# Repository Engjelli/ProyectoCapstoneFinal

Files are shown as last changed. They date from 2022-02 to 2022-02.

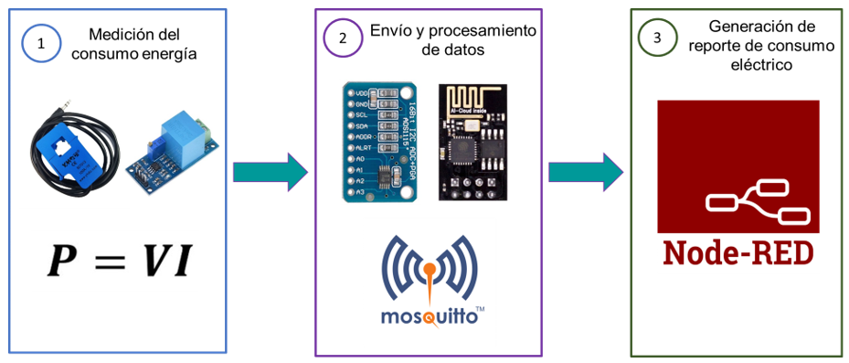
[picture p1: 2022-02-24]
Imagenes/Imagenes_reporte/01_diagrama_bloques_proyecto.PNG

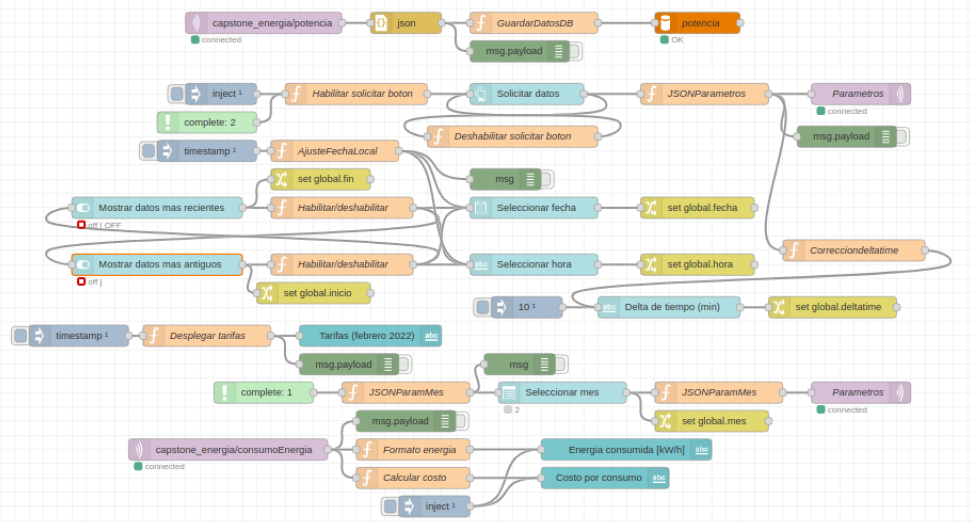
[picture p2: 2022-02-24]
Imagenes/Imagenes_reporte/08_flow_Node_Red1.PNG

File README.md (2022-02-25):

# ProyectoCapstoneFinal
Este proyecto muestra los patrones de consumo eléctrico durante el uso de los ordenadores.

**Nombre del proyecto**: Sistema de monitoreo sobre el consumo energético en ordenadores por medio del IoT

**Fecha de inicio del proyecto**: 12/12/21

**Fecha de conclusión del proyecto**: 22/02/22

**Descripción**: El equipo muestra los patrones de consumo eléctrico durante el uso de los ordenadores.

**Aplicaciones**: Delimitación a uso en ordenadores

## Objetivo general

 - Evaluar cuantitativamente el desempeño energético en ordenadores por medio del monitoreo de datos haciendo uso de plataformas y herramientas IoT.

## Objetivos particulares

 - Determinar el consumo energético en ordenadores a partir de las mediciones de voltaje y corriente almacenadas en una base de datos. 
 
 - Analizar los datos de consumo energético por medio de cálculos y gráficas con las mediciones  - almacenadas en la base de datos. 
 
 - Monitorear recursos de hardware y desempeño energético en ordenadores a través de Node Red utilizando paneles de control personalizados.

## Justificación

Si utilizamos una PC para tareas básicas como procesamiento de textos o incluso poder revisar nuestras redes sociales es probable que nuestro ordenador no demande demasiada energía. No obstante, si se trata de tareas más exigentes como edición de video, juegos o algún software en específico pueden causar un aumento considerable en el consumo de energía, además de un incremento en los costos en el recibo de luz. 

Por consiguiente, el sistema de monitoreo que se propone tiene como finalidad apoyar a los usuarios de una oficina, empresa e incluso en un hogar que cuenten con varios ordenadores conocer su consumo energético. Con base en esta información se puede evaluar y tomar las medidas necesarias para poder disminuir dicho consumo y reducir los costos en el recibo de luz. 

## Integrantes del equipo

María de los Ángeles Lino Suárez. 

Github: https://github.com/Engjelli

Jessica Arzate Martínez. 

Github: https://github.com/Jessica2123

Fernando Daniel Ramírez Cruz. 

Github: https://github.com/ferdanrc

**Validado por**: Paloma Vilchis y Hugo Vargas

## Contenido temático

**Productos**: 

**Alcances**: 
 - Oficinas inteligentes.
 - Infraestructuras on-premise.
 - Conocer patrones en consumo de energía.

## Funcionamiento del proyecto

Video del funcionamiento del proyecto: https://youtu.be/SWLC1IwsTZM

## Requisitos

### Hardware

**1. Alimentación del circuito 5V y 3.3V**

 - Cargador USB
 - Conector USB
 - Fuente 3.3V
 - Contacto para soldar
 - Cable duplex
 - Cable con clavija

**2. Módulos de interface  y conversión de datos**

 - Microcontrolador
 - ADC
 
**3. Sensores y material de acoplamiento**

 - Sensor de corriente
 - Sensor Voltaje
 - Jack Hembra 3.5mm
 - Cables Dupont
 
**4. Componentes para filtros y conexión del circuito**

 - Resistencias 
 - Capacitores 
 - Push button
 - Interruptor
 - Alambre Negro
 - Alambre Rojo

**5. Material para la carcasa del circuito**

 - Gabinete
 - Soldadura
 - Protoboard
 - Base para CI
 - Header Macho
 - Header Hembra

### Software

 - Node Red
 - Arduino con librerias MQTT y ESP8266

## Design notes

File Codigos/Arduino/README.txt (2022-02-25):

#README

##Instalacion de librerias

Instalar tarjeta para el ESP01 (basado en ESP8266):

http://arduino.esp8266.com/stable/package_esp8266com_index.json

Instalar las librerias:

 - Wire
 - EspMQTTClient

##Para cargar programas al ESP01

 1. Verificar que el pin 5 (GPIO0) esté conectado a tierra (colocar el switch correspondiente a tierra) para programarlo. 
 2. Presionar el botón de reset (push button para el pin 6). Aparece un mensaje en el puerto serial del IDE del Arduino a 74880 baud que indica que está en "boot mode".
 3. Cargar el programa. 

##Para ejecutar programas en el ESP01

 1. Al correr el programa, conectar el pin 5 (GPIO0) al ADS1115. 
 2. Presionar el botón de reset (push button para el pin 6). Aparece un mensaje en el puerto serial del IDE del Arduino a 74880. 
 3. El programa debe ejecutarse.

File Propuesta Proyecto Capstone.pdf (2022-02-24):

## Proyecto Capstone

Nombre:

Sistema de monitoreo sobre el consumo energético en ordenadores por medio del IoT

Asesora:

Vilchis León Paloma Alejandra

Integrantes:

Ramírez Cruz Fernando Daniel

Lino Suárez María de los Ángeles

Arzate Martínez Jessica

## Contenido

### 6.2.2 Convertidor analógico/digital externo, utilizando protocolo de

### 1. Introducción

Hoy en día la tecnología es necesaria en el ambiente profesional y personal, tanto que la mayoría de los dispositivos necesitan estar conectados a una toma corriente o ser cargados, diferente al siglo XIX en México donde solo se necesitaba la energía para iluminar las calles y viviendas en las noches. Actualmente hay muchos dispositivos que consumen energía eléctrica, lo que ha provocado que este consumo aumente y por tanto también los gastos por consumo eléctrico.

Los ordenadores se utilizan cotidianamente, entonces conocer su consumo de energía por máquina, por ejemplo en una oficina, puede optimizar el consumo de kWh y por lo tanto ahorrar así cómo planear su uso. El consumo de un ordenador puede convertirse en un indicador importante en términos de gastos de luz al año. Incluso, este cálculo puede ser significativo en lugares donde haya varios ordenadores, el costo por consumo eléctrico puede dispararse si no se tiene control sobre su uso, sobre todo si son potentes [1].

En este proyecto se pretende implementar un sistema de monitoreo sobre el consumo de energía en ordenadores haciendo uso de las herramientas y plataformas que nos proporciona el IoT. La delimitación del ambiente es un conjunto de varias computadoras funcionando de manera simultánea, por medio de sensores se obtendrán mediciones de corriente-voltaje, con los cuales se realizarán algunos cálculos de potencia que permitirán conocer el consumo energético en dichos equipos.

### 2. Objetivo general

Evaluar cuantitativamente el desempeño energético en ordenadores por medio del monitoreo de datos haciendo uso de plataformas y herramientas IoT.

### 3. Objetivos específicos:

1. Determinar el consumo energético en ordenadores a partir de las mediciones de voltaje y corriente almacenadas en una base de datos.
2. Analizar los datos de consumo energético por medio de cálculos y gráficas con las mediciones almacenadas en la base de datos.
3. Monitorear recursos de hardware y desempeño energético en ordenadores a través de Node Red utilizando paneles de control personalizados.

### 4. Justificación

Los ordenadores se han convertido en una parte integral de la sociedad actual. Son máquinas indudablemente poderosas y versátiles y se utilizan para realizar diversas tareas, desde trabajar hasta entretenimiento. Sin embargo, nunca nos preguntamos cuánta energía se puede consumir al realizar diversas tareas en dichos dispositivos [2].

Si utilizamos una PC para tareas básicas como procesamiento de textos o incluso poder revisar nuestras redes sociales es probable que nuestro ordenador no demande demasiada energía. No obstante, si se trata de tareas más exigentes como edición de video, juegos o algún software en específico pueden causar un aumento considerable en el consumo de energía, además de un incremento en los costos en el recibo de luz.

Por consiguiente, el sistema de monitoreo que se propone tiene como finalidad apoyar a los usuarios de una oficina, empresa e incluso en un hogar que cuenten con varios ordenadores conocer su consumo energético. Con base en esta información se puede evaluar y tomar las medidas necesarias para poder disminuir dicho consumo y reducir los costos en el recibo de luz.

Este sistema permite almacenar datos de corriente y voltaje de los equipos haciendo uso de diversas plataformas y herramientas que nos proporciona el Internet de las cosas. Se realizarán algunos cálculos de potencia los cuales permitirán conocer el consumo energético. Los datos obtenidos podrán ser analizados e interpretados haciendo uso de bases de datos y gráficas para generar informes sobre el consumo diario de los equipos. Además, se podrán conocer los procesos de los ordenadores que puedan estar generando un incremento en el consumo de energía.

Si bien, sería complicado dejar de usar nuestros ordenadores por completo dada la situación actual, el poder conocer el consumo energético podría ayudar a que formemos mejores hábitos de uso de dichos equipos. Por ejemplo, si el equipo no se está utilizando no tendría que estar encendido, eliminar procesos que no se utilicen y puedan estar generando mayor consumo, o si se están realizando tareas automáticas podríamos apagar el monitor de nuestra PC.

### 5. Material necesario

La lista de material se presenta a continuación:

- 1 Computadora de bajo costo (Raspberry Pi 3B+)
- 1 Computadora con adaptador para toma de corriente

Adicionalmente, para el medidor de consumo eléctrico:

Medidor de potencia versión Protoboard y versión Impreso

Alimentación del circuito 5V y 3.3V

Notas | Componente | Modelo/Valor | Cantidad | Precio | Subtotal
| Cargador USB | 5V @ 1A | 1 | 95 | 95
(Opcional)** | Conector USB | | 1 | 25 | 25
| Fuente 3.3V | AMS1117 | 1 | 47 | 47
| Contacto para soldar | | 1 | 29 | 29
| Cable duplex | Calibre 18 | 1 | 13 | 13
| Cable con clavija | 1.5m, calibre 18 | 1 | 35 | 35

Módulos de interface y conversión de datos

Microcontrolador | ESP01 | 1 | 59 | 59
ADC | ADS1115 | 1 | 130 | 130

Sensores y material de acoplamiento

Sensor de corriente | SCT013 | 1 | 134 | 134
Sensor Voltaje | ZMPT101B | 1 | 64 | 64
Jack Hembra 3.5mm | | 1 | 9 | 9
Cables Dupont | MH 10cm | 1 | 20 | 20
HH 10cm | 1 | 20 | 20

Componentes para filtros y conexión del circuito

Resistencias | 10k | 6 | 0.7 | 4.2
| R5* | 1 | 0.7 | 0.7
| 220k | 1 | 0.7 | 0.7
Capacitores | 10n | 1 | 2 | 2
| 10uF | 2 | 2 | 4
| 22uF | 1 | 2 | 2
| 100uF | 2 | 3 | 6

Push button | Microswitch 2 pines | 1 | 1 | 1
Interruptor | 1P2T | 1 | 4 | 4
Alambre Negro | 1m | 1 | 3 | 3
Alambre Rojo | 1m | 1 | 3 | 3
Material para la carcasa del circuito
*** | Gabinete | 15x6x9.9 cm | 1 | 179 | 179
| Soldadura | 17 gramos, 60/40 | 2 | 39 | 78
v.Protoboard | Protoboard | 400 puntos | 1 | 29 | 29
v.Impreso | Base para CI | 8 pines | 1 | 5 | 5
| Header Macho | 2x3 | 1 | 3 | 3
1x40 | 1 | 4 | 4
| Header Hembra | 2x4 | 1 | 5 | 5

Precios revisados en UNit Electronics y Steren al 2 de febrero del 2022

Notas adicionales sobre herramientas utilizadas

Se requiere de cautín y soldadura para poder colocar algunos componentes, como el ADS1115, el sensor de corriente y el sensor de voltaje.

**Para abrir el cargador USB, se recomienda utilizar un sargento. Con el sargento se presiona en puntos débiles de la carcasa para abrirla

*** Se requiere un taladro, brocas y limas para colocar los componentes sobre el gabinete

Total(v.Protoboard)*** | 996.6
Total(v.Impreso)*** | 984.6

Costos de envió
Tienda | Precio
UNIT Electronics | 50
Electrónica Steren | Gratis (mayor a 500$)

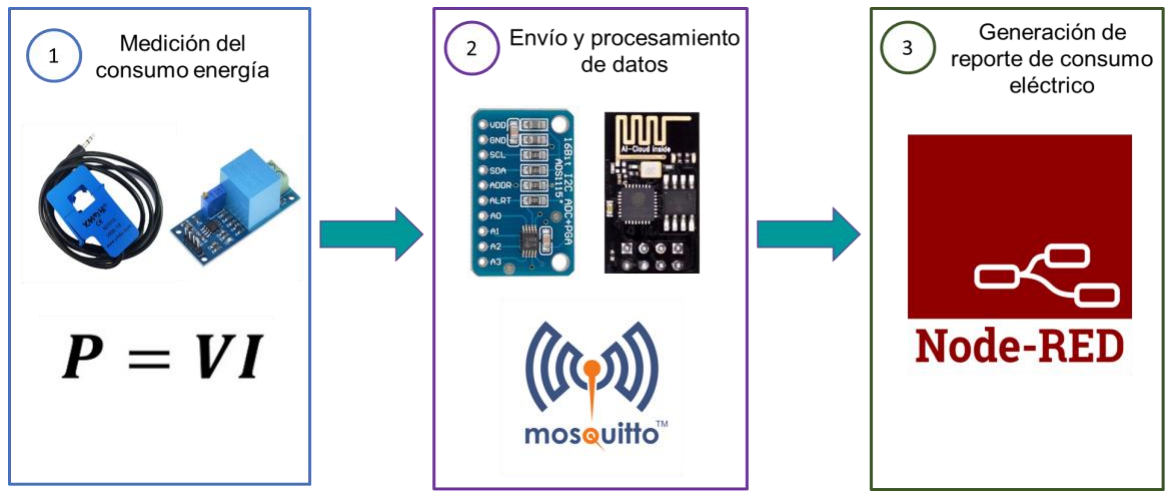
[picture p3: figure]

Fig. 1 Diagrama a bloques del sistema de monitoreo sobre el consumo energético en ordenadores.

### 6. Descripción del proyecto

El diagrama a bloques que representa al sistema de monitoreo sobre el consumo energético en ordenadores, es el siguiente:

A continuación, se realiza de forma general la descripción de cada uno de los bloques que conforman al sistema de monitoreo del consumo energético en ordenadores.

### 6.1 Medición del consumo de energía

En esta etapa se mide voltaje y corriente por medio de sensores y se agregan filtros para separar el ruido de las señales, y así obtener mediciones más confiables. Se presenta el diagrama esquemático completo utilizado:

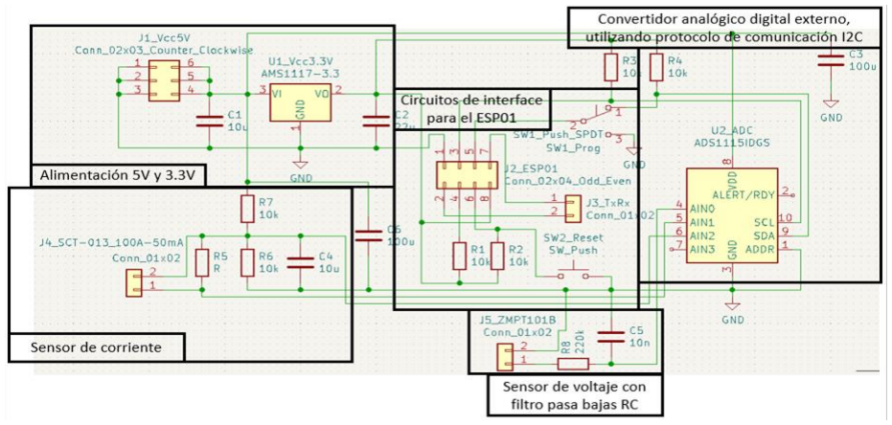
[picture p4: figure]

El circuito completo se compone de las siguientes partes:

2. Alimentación 5V y 3.3V: Contiene los circuitos de alimentación de todo el circuito.
3. Sensor de corriente: Incluye los circuitos para convertir la señal de corriente en señal de voltaje proveniente del sensor de corriente.
4. Sensor de voltaje: Contiene los circuitos y el filtro pasa bajas para el sensor de voltaje.
5. Convertidor analógico digital: Contiene los circuitos para adquirir las señales de los sensores de corriente y voltaje.
6. Circuitos de interface para el ESP01: Contiene los circuitos para cargar programas al ESP01.

A continuación, se realiza una breve explicación del circuito para cada uno de los sensores.

Fig. 2 Diagrama esquemático completo

### 6.1.1 Sensor de corriente

El sensor de corriente utilizado es el SCT-013 de 100A a 50mA. Para ello se utilizan las resistencias R5, R6, R7 y el capacitor C4 mostrados en la figura 3.

- Puesto que este sensor da como salida una corriente de hasta 50mA, se convierte esta señal de corriente en voltaje con la resistencia R5.

Las resistencias R6 y R7 forman un divisor de voltaje para el voltaje de alimentación de 5V, que servirá como voltaje de offset para montar la señal de corriente convertida a voltaje y que pueda ser leída por el convertidor analógico digital ADS1115.

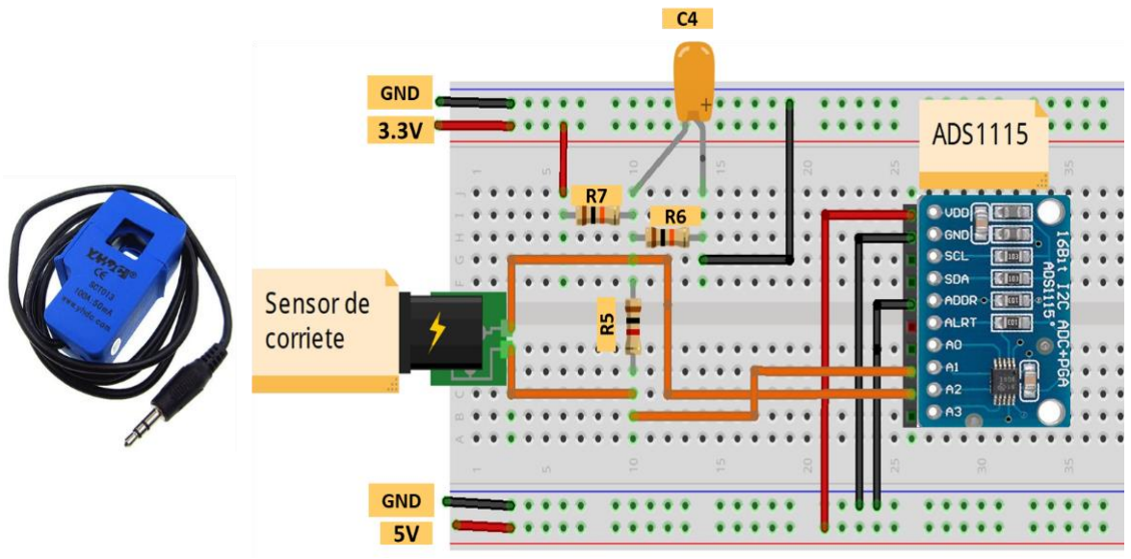
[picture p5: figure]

Fig. 3 Diagrama de conexión sensor de corriente SCT-013 100A/50MA y el ADS1115v

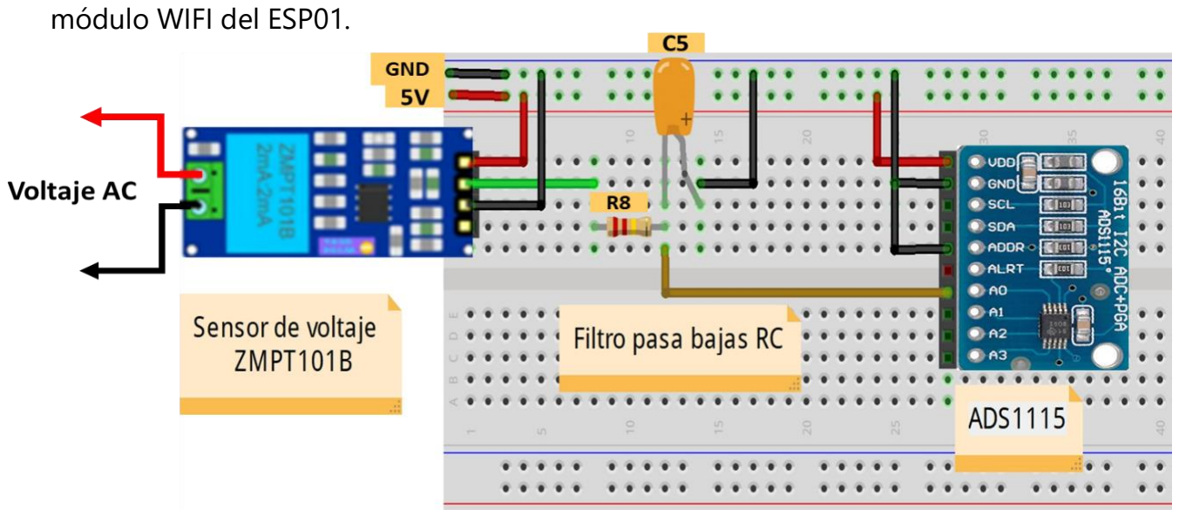
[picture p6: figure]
módulo WIFI del ESP01.

Fig. 4 Diagrama de conexión sensor de voltaje ZMPT101B.

### 6.1.2 Sensor de voltaje

El sensor de voltaje utilizado es el ZMPT101B. Este sensor tiene como salida una señal senoidal de voltaje montada sobre una componente de offset de alrededor 2.5V (aproximadamente la mitad del voltaje de alimentación de 5V).

Se utiliza un filtro RC pasa bajas formado por la resistencia R8 y por el capacitor C5 para reducir el ruido producido por inducción electromagnética cuando se utiliza el

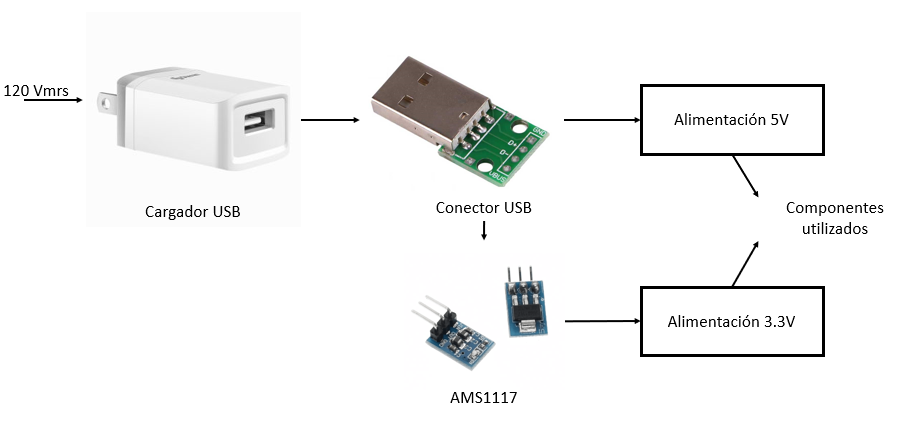
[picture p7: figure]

Fig. 5 Diagrama del circuito de una fuente de alimentación de 3.3V y 5V para alimentar los sensores.

### 6.1.3 Alimentación 5V y 3.3V

Para alimentar estos circuitos, se deben obtener voltajes de alimentación de 5V y 3.3V. Para ello se utilizan los siguientes componentes:

- Alimentación de 5V: Se utiliza el cargador USB junto con el conector USB para obtener un voltaje de 5V.
- Alimentación de 3.3V: A la salida del conector USB se conecta el circuito AMS1117 para obtener una salida de 3.3V.

Adicionalmente se utilizan los capacitores C1 y C2 para estabilizar los voltajes de alimentación.

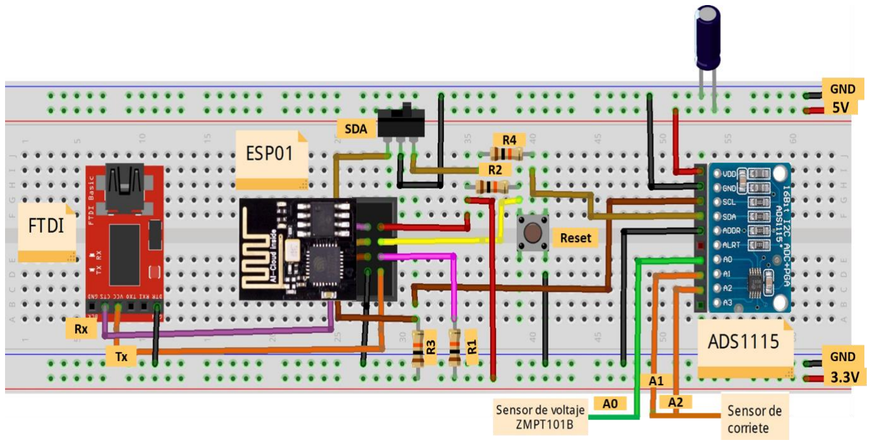
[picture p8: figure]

Fig. 6 Diagrama de conexión ESP01, ADS1115, FTDI.

### 6.2 Envío y procesamiento de datos

En este bloque se programa el microcontrolador ESP8266 que se encuentra en el módulo wifi ESP01 para realizar la transmisión y recepción de datos a través del protocolo de red MQTT con la ayuda de un convertidor analógico digital externo ADS1115 y utilizando el protocolo de comunicación I2C.

A continuación, se presenta el diagrama a bloques del programa cargado al ESP01 utilizado para adquirir las señales de los sensores de voltaje y corriente para calcular datos de potencia y energía.

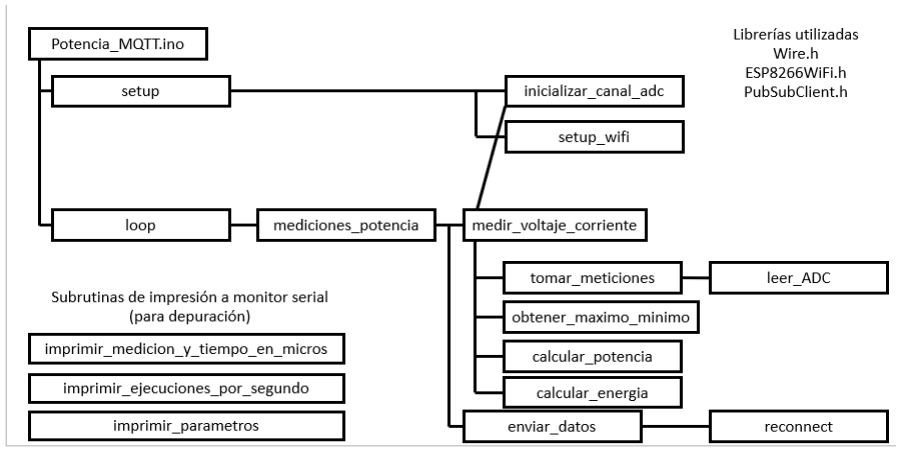
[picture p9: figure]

Fig. 7 Diagrama del programa realizado en Arduino.

### 6.2.1 Circuitos de interface para el ESP01

En esta parte está el hardware necesario para cargar programas al ESP01 (ver figura
6) y comunicar el ESP01 con el convertidor analógico digital ADS1115. Se utilizan los siguientes componentes:
- Para programar el ESP01 se utilizan los interruptores SW1 (SDA) y SW2 (botón de reset), las resistencias R1 y R2.
- Para comunicar el ESP01 con el convertidor analógico digital se utilizan las resistencias R3 y R4 que funcionan como resistencias de pull up necesarias para la comunicación por protocolo I2C.

Para programar el ESP01 se necesita que el interruptor SW1 (SDA) esté conectado a tierra y presionar brevemente el interruptor SW2 (botón de reset) para que se puedan cargar programas al ESP01.

Para ejecutar los programas cargados al ESP01 se necesita que el interruptor SW1 esté conectado al pin SDA del convertidor ADS1115 y a la resistencia R4 y presionar brevemente el interruptor SW2 (botón de reset).

### 6.2.2 Convertidor analógico/digital externo, utilizando protocolo de

comunicación I2C.

El convertidor analógico digital usado es el ADS1115, el cual cuenta con 4 canales de conversión y se comunica con el ESP01 mediante protocolo I2C.

- Los pines SCL y SDA van conectados a los pines 3 y 5 del ESP01.
- El pin ADDR está conectado a tierra, por lo que la dirección I2C para acceder el convertidor analógico digital ADS1115 es la 0x48.

El convertidor analógico digital recibe tres señales:

- En el canal AIN0 se recibe la señal de voltaje proveniente del sensor de corriente.
- En el canal AIN1 se recibe la señal de voltaje proveniente del sensor de voltaje.
- En el canal AIN2 se recibe el voltaje de offset utilizado para la señal de corriente.

### 6.3 Generación de reporte del consumo eléctrico

Por último, en Node-Red se realiza una conexión con MQTT al tema “capstone_energia/potencia”. Con los datos recibidos, se conecta a una base de datos a la tabla correspondiente. Posteriormente, con los datos que se recabaron en la base de datos se podrán realizar cálculos de potencia, los cuales serán graficados para poder realizar el análisis de dichos datos y determinar el consumo de energía en los ordenadores que se estén monitoreando.

Esta base de datos en mariadb utiliza como servidor a la Raspberry Pi3B+. En ella hay una base de datos llamada “potencia” y hay una tabla por cada una de las computadoras de las que se midió su consumo eléctrico.

Tablas de la base de datos: “potencia”

DELL_PC1

DELL_PC2

HP_PC1

Todas las tablas contienen la siguiente información de su computadora correspondiente:

Columna | fecha
| (datetime)

potencia

(float)

energía

(float)

Metadato | Fecha y hora de la medición de potencia y energía de la computadora correspondiente
Potencia
promedio en 10
segundos de la
computadora
correspondiente

Energía
consumida en 10
segundos de la
computadora
correspondiente

Tabla 1. Tablas contenidas en la base de datos “potencia”.

Tabla 2. Contenido de todas las tables de la base de datos “potencia”.

En Node-Red se realiza una conexión con MQTT a diversos temas para el intercambio de información entre Node-Red y la base de datos mariadb.

- En el tema “capstone_energia/parametrosGraficas” se envían los parámetros necesarios desde Node Red hacia Python. Python se encarga de la conexión a la base de datos para adquirir los datos solicitados.
- En | el | tema | “capstone_energia/datosPotencia” | y
“capstone_energia/datosEnergia” se reciben en Node-Red los datos extraídos de la base de datos. Estos datos son graficados.
- Adicionalmente, en el tema “capstone_energia/nombreTablas” se reciben los nombres de todas las computadoras que se están monitoerando.
- En el tema “capstone_energia/consumoEnergia” se recibe el consumo de energía total mensual de una computadora en particular.

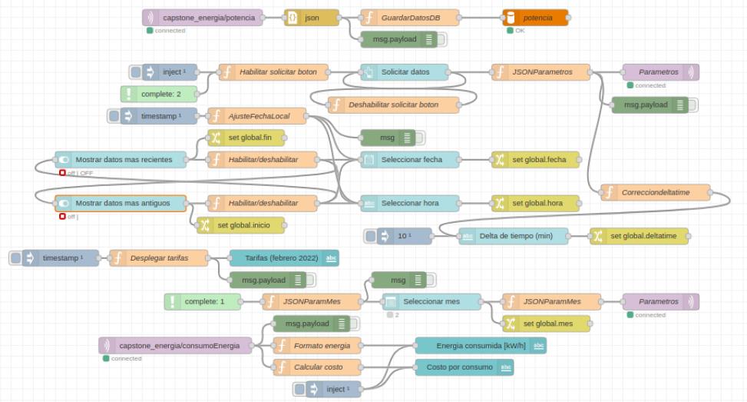
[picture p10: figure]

Fig. 8 Flow en Node-Red (1).

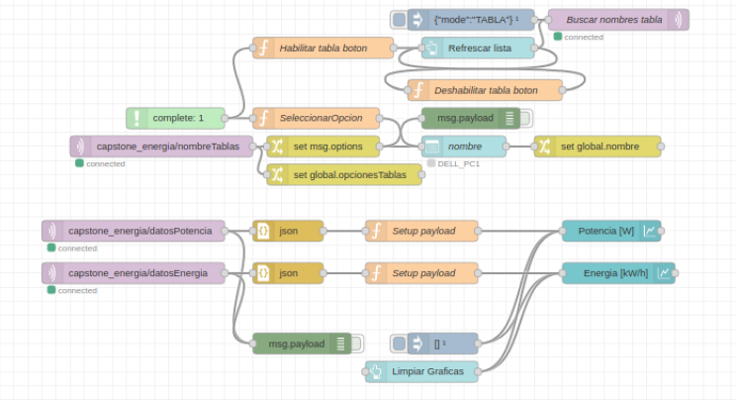
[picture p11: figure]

El panel de Node-Red hay 4 conjuntos de controles:

- En el grupo “Seleccionar PC” el usuario selecciona la computadora de la cual se desplegará información sobre su consumo eléctrico.
- En el grupo “Costo por consumo de energía” el usuario puede observar el consumo de energía mensual de la computadora seleccionada, al igual que el costo asociado a este consumo de energía.
- En el grupo “Seleccionar ventana de tiempo para las gráficas” el usuario puede seleccionar la fecha, hora y un intervalo de tiempo para visualizar gráficamente el comportamiento del consumo eléctrico. El usuario también puede visualizar los datos más recientes seleccionando la opción “Mostrar datos más recientes” o bien, también puede seleccionar los datos más antiguos seleccionando la opción “Mostrar datos más antiguos”.
- En el grupo “Gráficas del consumo de energía” se despliegan dos gráficas, la de potencia y energía. La gráfica de potencia, dada en Watts, despliega los datos de potencia promedio que consumió esa computadora en el intervalo de tiempo seleccionado. La gráfica de energía, dada en kW/h (kiloWatt hora), muestra el consumo total de energía en el mismo intervalo de tiempo anteriormente seleccionado.

Fig. 9 Flow en Node-Red (2).

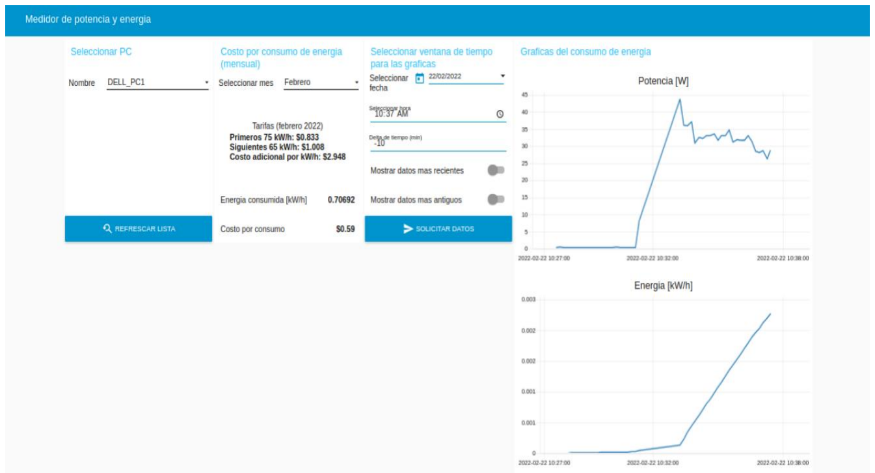
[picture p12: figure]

Fig. 10 Panel en Node-Red.

### 7. Conclusión

Se ha observado que el consumo eléctrico en ordenadores es poco con respecto a otros dispositivos electrodomésticos que conforman el consumo de energía total en el hogar. Sin embargo, es útil conocerlo, sobre todo, en un cuarto con muchas computadoras o en donde se tengan computadoras potentes.

Los ordenadores no son los únicos dispositivos que se pueden medir con el presente proyecto, porque con algunas modificaciones al presente proyecto, se puede medir otros dispositivos que consuman más energía, como son los electrodomésticos e incluso maquinaria industrial.

Por otro lado, es posible como trabajo futuro realizar análisis adicionales sobre los datos, para obtener, por ejemplo, patrones de consumo de energía, calcular tendencias de consumo y poder generar un plan de ahorro de consumo eléctrico para ordenadores.

### 8. Bibliografía

1. CHC Energía: https://chcenergia.es/blog/cuanto-consume-un-ordenador-o-pc/ (https://chcenergia.es/blog/cuanto-consume-un-ordenador-o-pc/)
2. HZ | hard | zone: | https://hardzone.es/tutoriales/mantenimiento/medir-
consumo-pc/ (https://hardzone.es/tutoriales/mantenimiento/medir-consumo-pc/)

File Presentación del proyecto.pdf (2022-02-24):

## Sistema de monitoreo sobre el consumo energético en

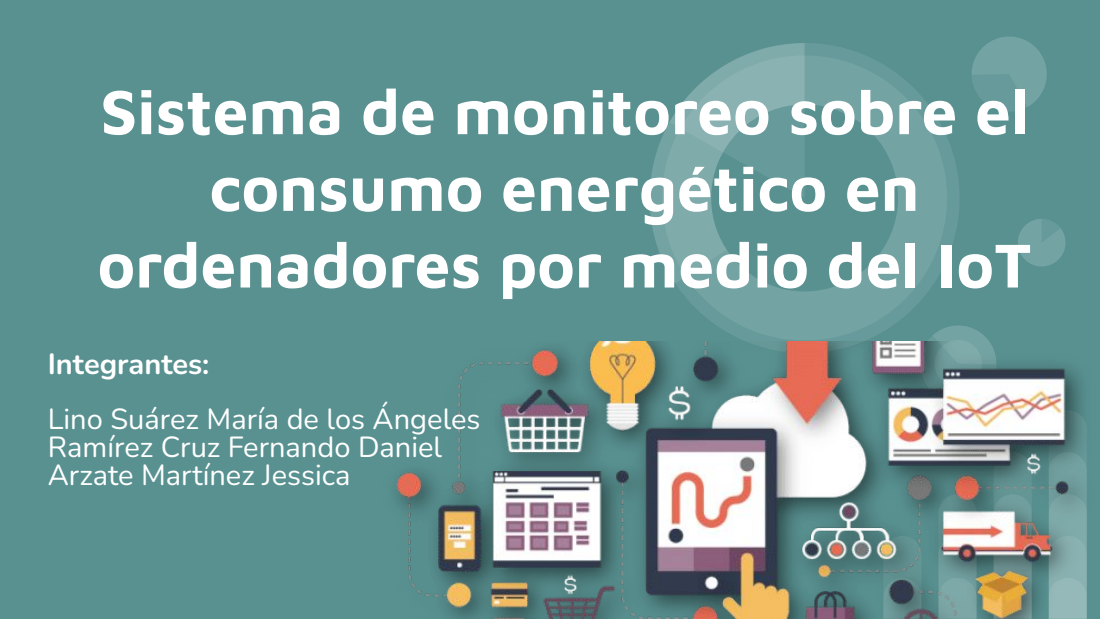
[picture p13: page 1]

ordenadores por medio del IoT

Integrantes:
Lino Suárez María de los Ángeles
Ramírez Cruz Fernando Daniel
Arzate Martínez Jessica

Planteamiento del problema

- Los costos por consumo eléctrico pueden llegar a ser muy variables y en algunos casos excesivos.
- En un día habitual las personas pueden llegar a utilizar los ordenadores por varias horas.
- Conocemos poco acerca del consumo de energía cuando hacemos uso de las computadoras.

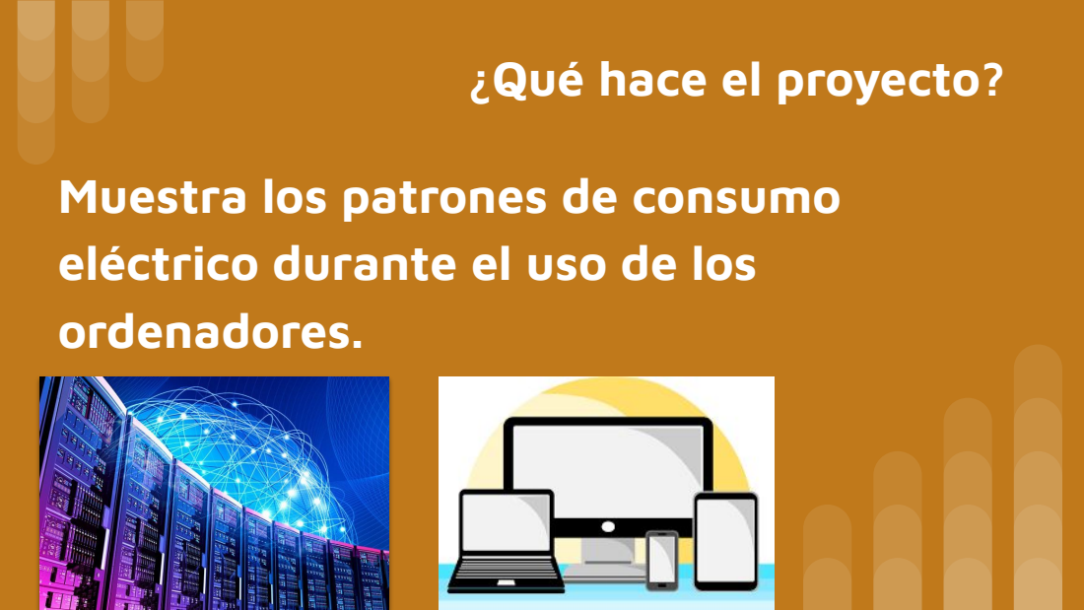
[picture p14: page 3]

¿Qué hace el proyecto?

Muestra los patrones de consumo
eléctrico durante el uso de los
ordenadores.

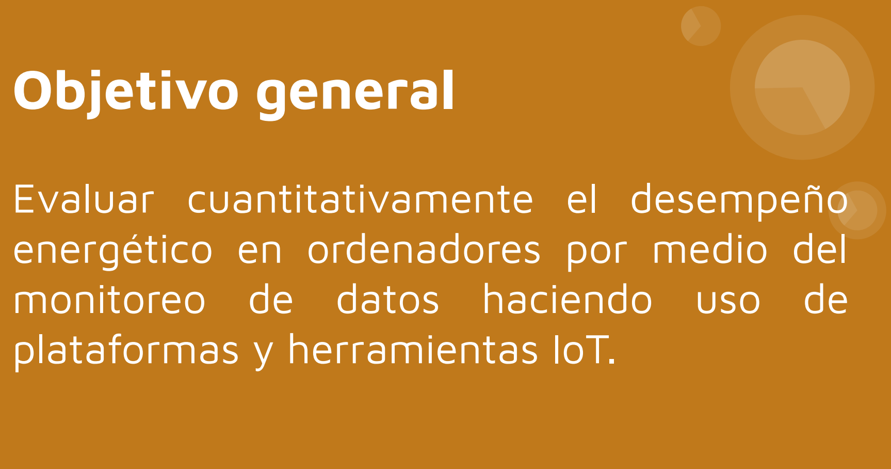
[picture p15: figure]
Objetivo general; Evaluar cuantitativamente el desempeño energético en ordenadores por medio del monitoreo de datos haciendo uso de plataformas y herramientas IoT.

Objetivos
particulares

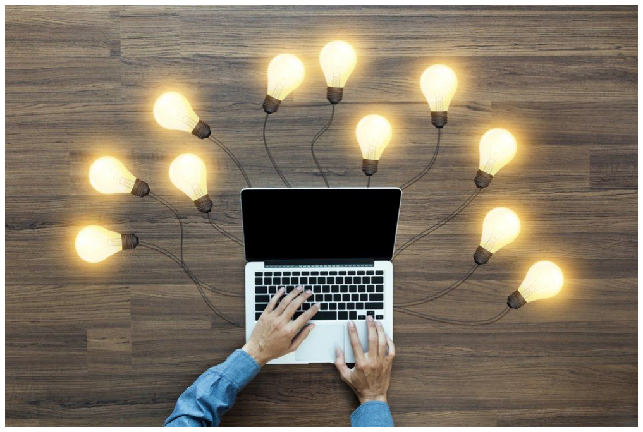
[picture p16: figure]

Determinar el consumo energético en ordenadores a partir de las mediciones de voltaje y corriente almacenadas en una base de datos.

Objetivos
particulares

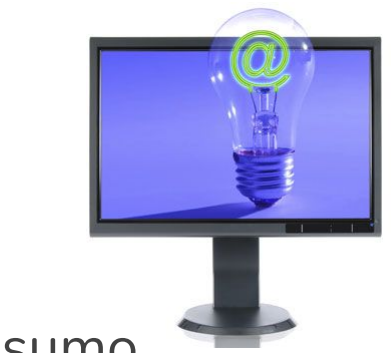
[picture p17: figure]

Analizar los datos de consumo energético por medio de cálculos y
gráficas | con | las | mediciones
almacenadas en la base de datos.

Objetivos
particulares

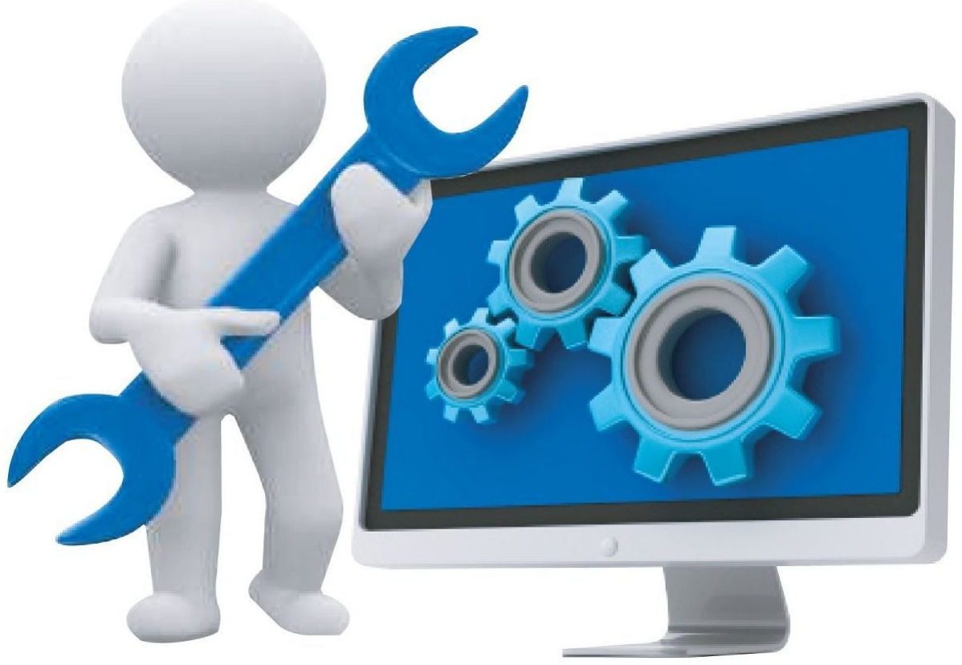
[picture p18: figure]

Monitorear recursos de hardware y desempeño energético en
ordenadores a través de Node Red utilizando paneles de control personalizados.

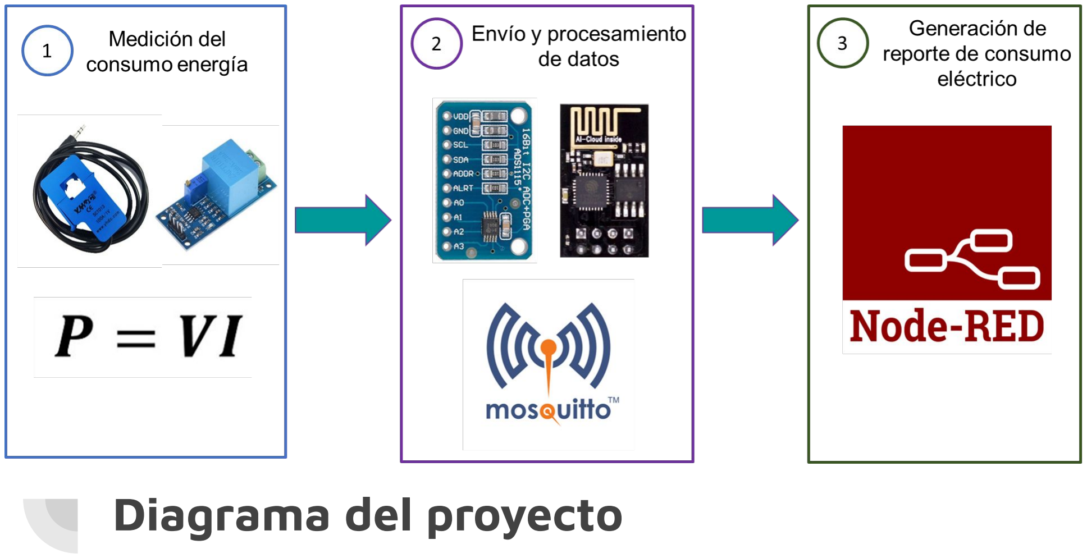
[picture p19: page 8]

Diagrama del proyecto

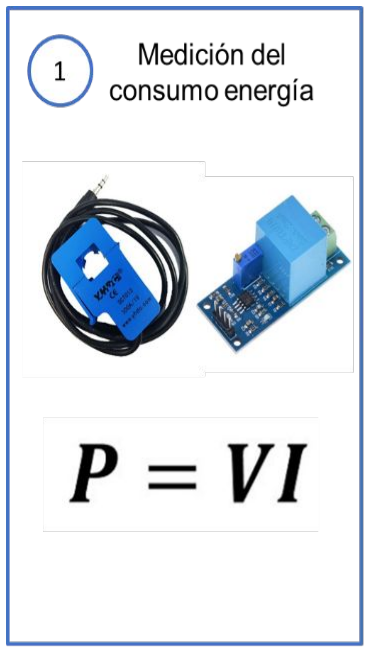
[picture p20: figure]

- Mide las variables de
voltaje y corriente por
medio de sensores.
- Agrega filtros para
separar el ruido de las
señales.

Medición de consumo de energía

Envío y procesamiento de datos

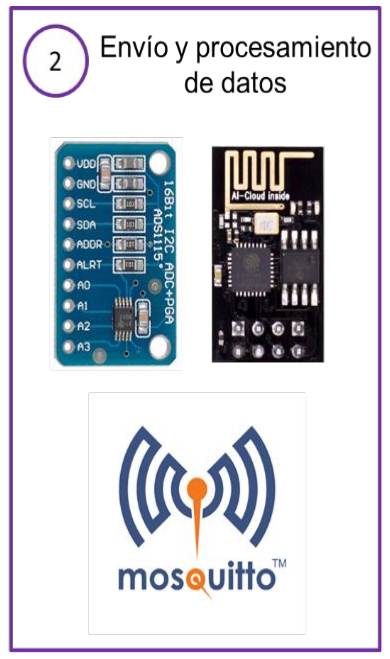
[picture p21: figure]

- Procesa los datos de
voltaje y corriente.
- Calcula del consumo
eléctrico.
- Envía los datos a un
servidor broker público.

Generación del reporte de consumo eléctrico

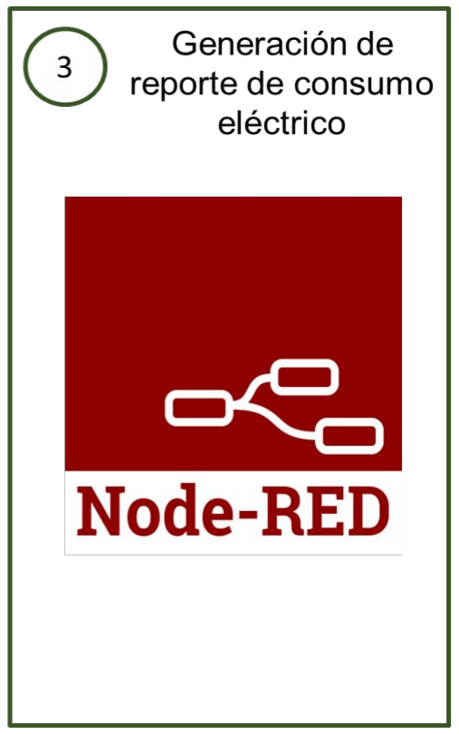
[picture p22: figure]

- Concentra los datos y
muestra un resumen del
consumo eléctrico.

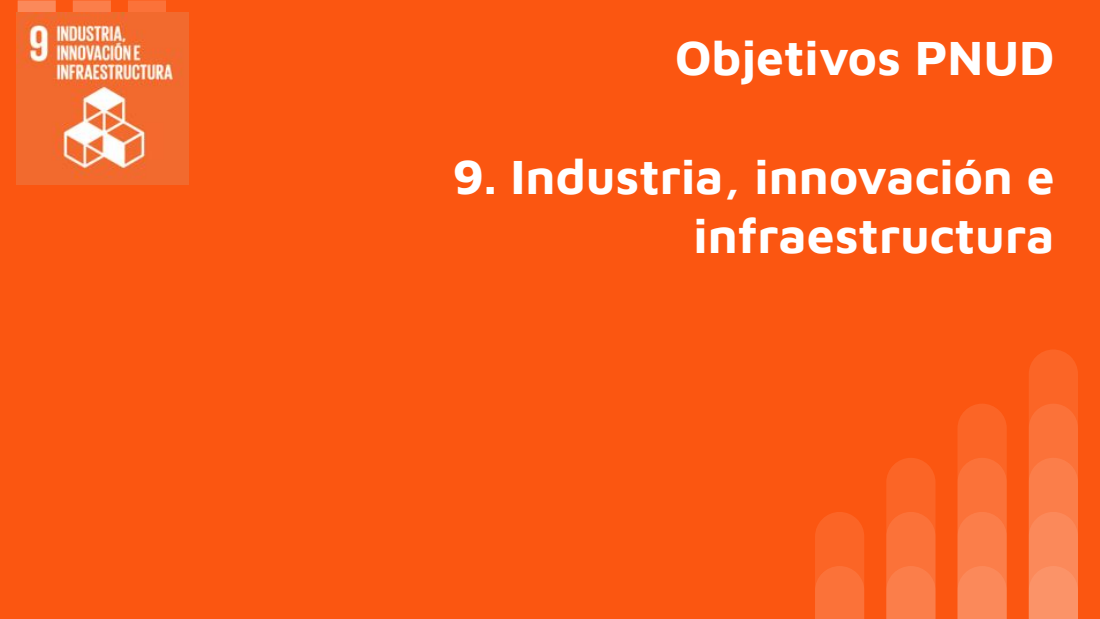
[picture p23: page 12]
Objetivos PNUD; 9. Industria, innovación e infraestructura

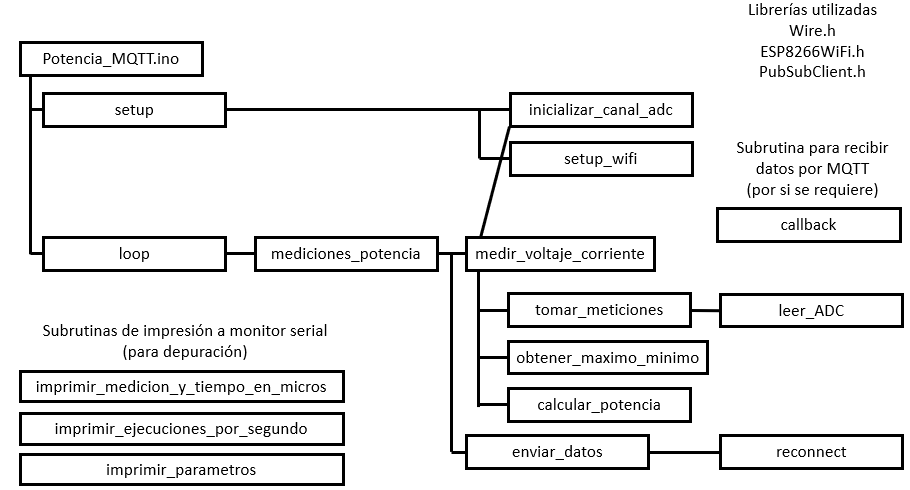
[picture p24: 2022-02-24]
Imagenes/Imagenes_reporte/07_diagrama_bloques_programa_ESP01.PNG

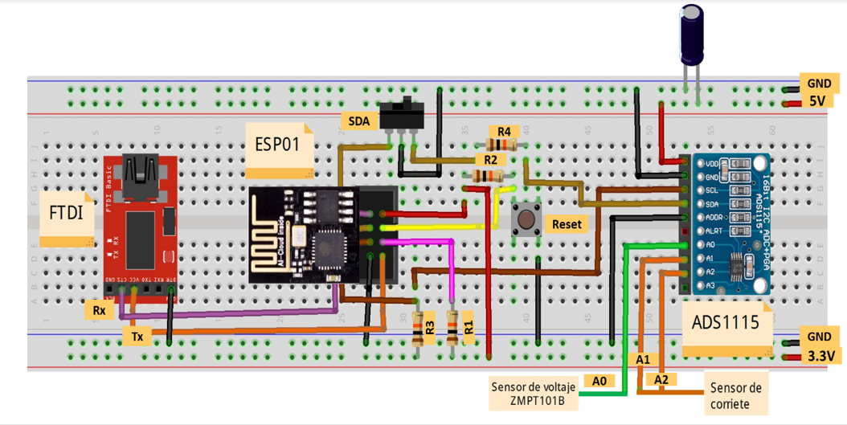
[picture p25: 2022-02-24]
Imagenes/Imagenes_reporte/06_diagrama_ESP01.PNG

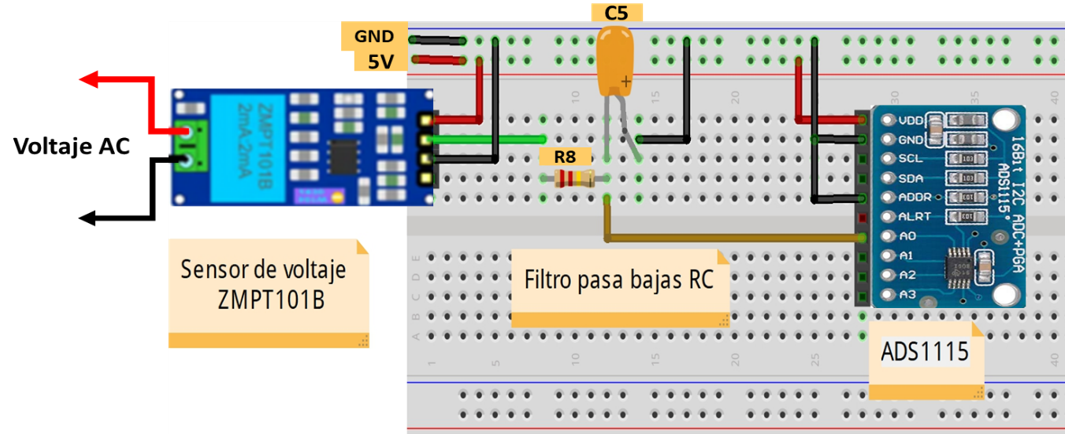
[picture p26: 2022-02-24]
Imagenes/Imagenes_reporte/05_diagrama_sensor_voltaje.PNG

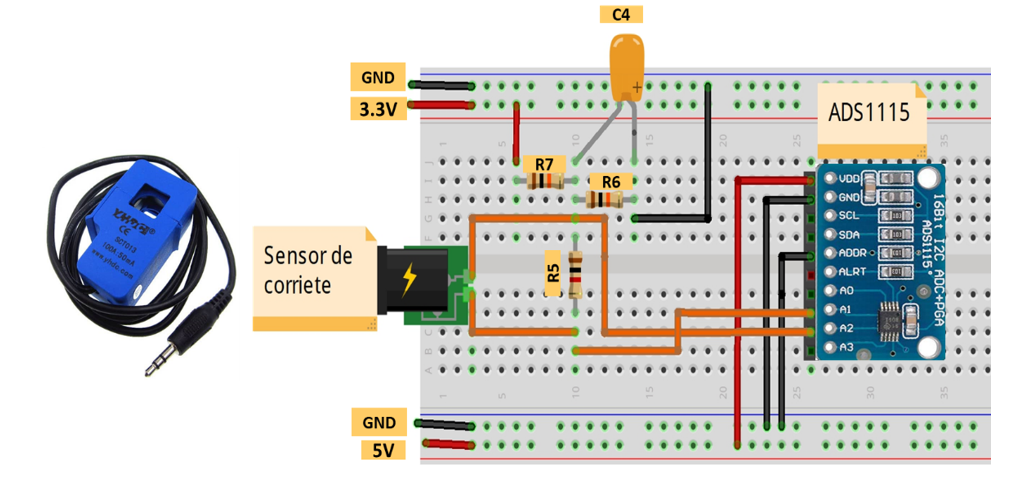
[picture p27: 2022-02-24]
Imagenes/Imagenes_reporte/03_diagrama_sensor_corriente.PNG

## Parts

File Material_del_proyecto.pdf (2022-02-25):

Notas | Componente | Modelo/Valor | Cantidad | Precio | Subtotal | Liga
Fuente 3.3V | AMS1117 | 1 | 47 | 47 https://uelectronics.com/producto/regulador-ams1117-5v-a-3-3v/
Microcontrolador | ESP01 | 1 | 59 | 59 https://uelectronics.com/producto/esp-01s-modulo-wifi-esp8266/
ADC | ADS1115 | 1 | 130 | 130 https://uelectronics.com/producto/modulo-ads1115-adc/
Sensor de corriente | SCT013 | 1 | 134 | 134 https://uelectronics.com/producto/sensor-de-corriente-sct-013-000-100a-50ma/
Sensor Voltaje | ZMPT101B | 1 | 64 | 64 https://uelectronics.com/producto/zmpt101b-sensor-de-voltaje-ac-2ma/
Jack Hembra 3.5mm | 1 | 9 | 9 https://www.steren.com.mx/jack-3-5-mm-estereo-encapsulado-para-chasis.html
MH 10cm | 1 | 20 | 20 https://uelectronics.com/producto/cables-dupont-cortos-10cm-hh-mh-mm/
HH 10cm | 1 | 20 | 20 https://uelectronics.com/producto/cables-dupont-cortos-10cm-hh-mh-mm/
Gabinete *** | 15x6x9.9 cm | 1 | 179 | 179 https://www.steren.com.mx/gabinete-plastico-de-15-x-6-x-9-9-cm.html
Alambre Negro | 1m | 1 | 3 | 3 https://uelectronics.com/producto/alambre-para-protoboard-negro-1-metro/
Alambre Rojo | 1m | 1 | 3 | 3 https://uelectronics.com/producto/alambre-para-protoboard-rojo-1-metro/
(Opcional)** Conector USB | 1 | 25 | 25 https://uelectronics.com/producto/adaptador-usb-tipo-a-macho-a-dip-pcb-4-pines/ | ** Se puede abrir el cargador USB y utilizar el circuito que viene adentro en vez de comprar este componente
Cargador USB | 5V @ 1A | 1 | 95 | 95 https://www.steren.com.mx/cargador-usb-rapido.html
Contacto para soldar | 1 | 29 | 29 https://www.steren.com.mx/contacto-para-chasis.html
Cable duplex | Calibre 18 | 1 | 13 | 13 https://www.steren.com.mx/cable-duplex-500-m-18-awg-bicolor-vta.html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
Cable con clavija | 1.5m, calibre 18 | 1 | 35 | 35 https://www.steren.com.mx/catalog/product/view/id/17619/s/cable-de-alimentacion-interlock-para-extension-de-1-5-m-18-awg/
Resistencias | 10k | 6 | 0.7 | 4.2 https://uelectronics.com/producto/resistencias-de-1-2w-desde-1-ohm-3-3m-ohm-1/
R5* | 1 | 0.7 | 0.7 https://uelectronics.com/producto/resistencias-de-1-2w-desde-1-ohm-3-3m-ohm-1/ | *Ver tabla para calcular valor de R5 al final de la lista de componentes
220k | 1 | 0.7 | 0.7 https://uelectronics.com/producto/resistencias-de-1-2w-desde-1-ohm-3-3m-ohm-1/
Capacitores | 10n | 1 | 2 | 2 https://uelectronics.com/producto/capacitor-ceramico-4-7-nf-a-1-uf/
10uF | 2 | 2 | 4 https://uelectronics.com/producto/capacitor-electrolitico-50v/
22uF | 1 | 2 | 2 https://uelectronics.com/producto/capacitor-electrolitico-50v/
100uF | 2 | 3 | 6 https://uelectronics.com/producto/capacitor-electrolitico-50v/
Push button | Microswitch 2 pines | 1 | 1 | 1 https://uelectronics.com/producto/push-boton-2-pines-microswitch-button/
Interruptor | 1P2T | 1 | 4 | 4 https://uelectronics.com/producto/interruptor-un-polo-dos-tiros/
Soldadura | 17 gramos, 60/40 | 2 | 39 | 78 https://www.steren.com.mx/tubo-de-17-gramos-de-soldadura-con-aleacion-esta-o-plomo-60-40.html
v.Protoboard Protoboard | 400 puntos | 1 | 29 | 29 https://uelectronics.com/producto/protoboard-400-pts/
Base para CI | 8 pines | 1 | 5 | 5 https://uelectronics.com/producto/base-socket-8-pines-para-circuito-integrado/
| 2x3 | 1 | 3 | 3 https://uelectronics.com/producto/tira-header-macho-doble-diferentes-pines-2-54mm/
| 1x40 | 1 | 4 | 4 https://uelectronics.com/producto/header-macho-tira-de-40-dupont-2-54mm-pin/
Header Hembra | 2x4 | 1 | 5 | 5 https://uelectronics.com/producto/tira-header-hembra-doble-diferentes-pines-2-54mm/
Costo de envio | Unit | 50 | 996.6
| Steren(mayor a 500$) | Gratis | 984.6

Al costo total, agregar (se consigue en tlapalerías):
Componente | Cantidad | 45
Gromet | 2 | 1200 | Vmax | 4.3039575
Bases de goma | 4 | 1.80395746 | Vmin | 0.6960425
Tornillos y tuercas | 5
Base para soldar | 1
Potencia | 45 | 65 | 100 | 150
R5 | 1200 | 680 | 470 | 330

Notas adicionales sobre herramientas utilizadas
**Para abrir el cargador USB, se recomienda utilizar un sargento. Con el sargento se presina en puntos débiles de la carcasa para abrirla *** Se requiere un taladro, brocas y limas para colocar los componentes sobre el gabinete

***

R5

Total(v.Protoboard)***
Total(v.Impreso)***

Agregar costos de placa impresa

Voltaje pico de salida (maximo)

Valores de ejemplo

*Tabla para determinar el valor de R5 | Vmax y Vmin deben de estar entre 0.5 y 4.5V
Potencia nominal del dispositivo | Vpico de salida debe ser mayor a 1
Medidor de potencia versión Protoboard y version Impreso | Precios revisados al 9 de febrero del 2022

Cables Dupont

v.Impreso Header Macho

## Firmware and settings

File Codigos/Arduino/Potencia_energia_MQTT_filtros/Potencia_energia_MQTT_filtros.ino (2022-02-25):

/*
 * Este programa realiza el calculo de potencia de un dispositivo a partir de las mediciones de voltaje y corriente
 * 
 * Por Fernando Daniel Ramírez Cruz
 * Basado en el progamas de: 
 * Lewis Loflin. Tomado de https://www.bristolwatch.com/arduino2/ard0.htm
 * Hugo Escalpelo. Tomado de https://github.com/hugoescalpelo/ESP32CAM-WiFi-Basic/blob/main/ESP32CAM-WiFi-Basic/ESP32CAM-WiFi-Basic.ino
 */

/*
 * DESCRIPCION DEL PROGRAMA:
 * 
 * 
 * Cada 870 us se toma una muestra, ya sea de voltaje o corriente
 * 
 * La frecuencia de la red electrica es de 60Hz o 16.6 ms
 * Por cada ciclo (cada 16.6 ms) se toman 18 muestras (18 * 870 us = 15.66 ms, que es menor que 1/60 s)
 * 
 * Por cada 4/60 de segundo (66.6 ms para 4 ciclos de 60Hz) se toman (18*4)-2=74 muestras
 * Cada 66 ms se realiza un calculo de potencia y se alterna entre lectura de muestras de voltaje y corriente 
 * Es decir, 66.6 ms para tomar muestras de corriente y 66.6 ms para tomar muestras de voltaje. Este proceso se repite indefinidamente
 * Se realizan 15 calculos de potencia por segundo. 
 * 
 * Cada 10 segundos se realiza un promedio de los 150 calculos de potencia realizados
 * 
 * Para calcular la potencia se realiza lo siguiente:
 * Identificar la muestra con el valor mayor y con el valor menor
 * Elevar al cuadrado cada muestra de voltaje y sumarlas. Elevar al cuadrado cada muestra de corriente y sumarlas
 * Promediar la suma de cuadrados de voltaje. Promediar la suma de cuadrados de corriente
 * Vrms = Sacar la raiz cuadrada del promedio de la suma de cuadrados de voltaje. Irms = Sacar la raiz cuadrada del promedio de la suma de cuadrados de corriente. 
 * Realizar P = Vrms * Irms / 2, donde P es la promedio de la protencia que consume ese dispositivo
 * 
 * Adicionalmente se calcula la energia en Joules:
 * Multiplicar la muestra de potencia calculada por el tiempo que dura esa muestra (4/60 de segundo o 1 segundo entre 15 muestras)
 * Sumar todos los calculos de energia por 10 segundos
 * 
 * 
 * NOTAS ADICIONALES
 * 
 * Tiempo minimo para realizar una medicion: 820 - 830 us sin utilizar la libreria ADS11X5.h
 * NO UTILIZAR LA LIBRERIA ADS11X5.h ya que es muy lenta, tarda alrededor de 10ms en tomar una muestra
 * Se requiere un minimo de 8.3 ms para tomar al menos 2 muestras por ciclo
 * 
 * Las señales leidas del ADS1115 tienen una componente de voltaje de offset equivalente a Vcc/2, donde Vcc es el voltaje de alimentacion que se utiliza para alimentar el sensor de voltaje y el sensor de corriente
 * Puesto que para el voltaje se identifica la muestra con valor maximo y minimo, se puede calcular el valor medio de esta manera: voltaje_offset = (maximo - minimo)/2 + minimo
 * Para obtener la lectura verdadera de cada muestra que se mide de los sensores, se realiza: (medicion - voltaje_offset) * ganancia
 * 
 * La ganancia de voltaje se determino expermientalmente para el sensor ZMPT101B y puede variar entre 800 y 1100 aproximadamente (incluye la ganancia por el filtro RC)
 * La ganancia de corriente depende de la resistencia que se utilice para el sensor SCT013(100A/50mA) 
 * Como este sensor SCT013 da una salida de corriente, la resistencia utilizada convierte esta corriente en voltaje
 * La ganancia de corriente, utilizando una resistencia de 1Kohm es de apromadamente 2 (2000/1000)
 * 
 */


//Bibliotecas
#include <Wire.h> // Biblioteca para la comunicacion I2C
#include <ESP8266WiFi.h>  // Biblioteca para el control de WiFi
#include <PubSubClient.h> //Biblioteca para conexion MQTT

//Datos de WiFi
const char* ssid = "INFINITUMBF13_2.4";  // Aquí debes poner el nombre de tu red
const char* password = "0007213411";  // Aquí debes poner la contraseña de tu red


//Datos del broker MQTT
const char* mqtt_server = "3.126.191.185"; // Si estas en una red local, coloca la IP asignada, en caso contrario, coloca la IP publica

// para ubicar ip, ejecutar en una terminal nslookup broker.hivemq.com y colocar ip publica o privada
IPAddress server(3,126,191,185);

// Objetos
WiFiClient espClient; // Este objeto maneja los datos de conexion WiFi
PubSubClient client(espClient); // Este objeto maneja los datos de conexion al broker


//Variables para medir tiempo
unsigned long t_millis, t_micros, t_medicion, t_mediciones_tomadas, t_ciclo, t_calculo_potencia;
unsigned int count = 0;

//Constantes de tiempo
const int t_por_calculo_potencia = 10000000; // Cada 10 segundos se calcula un promedio de las potencias calculadas (en microsegundos)
const int t_por_ciclo = 16667; // Frecuencia de la señal electrica 60Hz (en microsegundos)
const int t_por_muestra = 870; // Tomar 19 muestras por ciclo (en microsegundos)

//Constantes para la tma de muestras
const int num_muestras = 18; // Muestras tomadas por ciclo (por cada 1/60 de segundo o 870us aproximadamente)
const int num_ciclos = 4; // Numero de ciclos para tomar voltaje o corriente
const int num_muestras_tomadas = (num_muestras * num_ciclos) - 2; // Total de muestras tomadas por cada num_ciclos. Las ultimas dos muestras no se toman. 

// variables para la toma de muestras
double muestras[num_muestras_tomadas] = {}; // arreglo con las muestras tomadas

// variables para el calculo de potencia
double potencia = 0; // calculo de potencia vrms*irms
double potencia_acc = 0; // acumula calculos de potencia
double potencia_prom = 0; // promedio de varios calculos de potencia

double energia = 0; // calculo de energia P*t
double energia_acc = 0; // acumula calculos de energia

double voffset = 2.5; // voltaje de offset sobre la que estan montadas las señales de voltaje y corriente
const double v_ganancia = 915; // ganancia del sensor de voltaje
const double i_ganancia = 2000/551; // ganancia del sensor de corriente

double maximo[2], minimo[2]; // Almacenan la muestra con valor maximo y con valor minimo
double v2 = 0, i2 = 0; // Muestra de voltaje al cuadrado y corriente al cuadrado
double vrms = 0, irms = 0; // voltaje rms y corriente rms
double voltaje = 0,corriente = 0; // Almacenan el valor de voltaje y corriente medido

byte i_muestra = 0, i_potencia = 0; // Iteradores para la toma de muestras y para los calculos de potencia
byte corriente_o_voltaje = 0; // indica si se debe tomar corriente o voltaje
byte corriente_offset = 0; 
double ioffset = 0;
double v_acc = 0;

byte i_num_muestras = 0;


// variables para la lectura del ADC
unsigned int val = 0; // Almacena la lectura del ADC
byte muestras_listas = 0; // Indica si todas las muestras ya fueron tomadas

const byte ASD1115 = 0x48; // Direccion I2C del ADC
const double VPS = 6.144 / 32768.0; // volts por paso

byte writeBuf[3]; // variable para escribir en el ADC
byte buffer[3]; // variable para recibir datos del ADC

/*
 * Se inicializa la comunicacion serial, la comunicacion i2c, el ADC y las variables de tiempo. 
 * 
 */
void setup()   {

  Serial.begin(115200); // Inicia el monitor serial a 115200 baud
  Wire.begin(0,2); // Inicializa la comunicacion I2C en los pines GPIO0 y GPIO2

  Serial.println();
  
  inicializar_canal_ADC(); // Inicializa un canal del ADC

  delay(1000);
  
  setup_wifi(); // Inicializa el Wifi y servidor MQTT
  client.setServer(server, 1883); // Conectarse a la IP del broker en el puerto indicado
  client.setCallback(callback); // Activar función de CallBack, permite recibir mensajes MQTT y ejecutar funciones a partir de ellos
  
  delay(1000);

  // Inicializa variables de tiempo
  t_micros = micros();
  t_millis = millis();
  t_mediciones_tomadas = micros();
  t_ciclo = micros();
  t_calculo_potencia = millis();
}  // end setup


void loop() {
  mediciones_potencia();
} // end loop

void mediciones_potencia(){
  
  medir_voltaje_corriente(); // Realiza mediciones de voltaje y corriente
  
  if((micros() - t_calculo_potencia) > t_por_calculo_potencia)
  {
    potencia_prom = potencia_acc / i_potencia; // Calcula la potencia promedio de las 150 muestras

    // Si por alguna razon las muestras fueron diferentes de 150, se realiza un ajute al calculo de energia
    if(i_potencia != 150)
    {
      energia_acc = energia_acc*150/i_potencia;
    }

    // Imprime potencia promedio, energia y numero de meustras
    Serial.print("Potencia (Vrms*Irms/2): "); Serial.println(potencia_prom);
    Serial.print("Energia (sum(P*t)): "); Serial.println(energia_acc);
    Serial.print("Muestras: "); Serial.println(i_potencia);
    //delay(2000);


    enviar_datos(); // envia los datos por mqtt

    // Limpia e inicializa variables
    energia_acc = 0;
    potencia_acc = 0;
    energia_acc = 0;
    
    i_potencia = 0;
    t_calculo_potencia = micros();
    t_ciclo = micros();
    t_mediciones_tomadas = micros();
  }
}


/**
 * Envia los datos de id de la maquina, potencia promedio y energia a traves del protocolo mqtt, utilizando un broker
 */
void enviar_datos(){
  //Verificar siempre que haya conexión al broker
  if (!client.connected()) {
    reconnect();  // En caso de que no haya conexión, ejecutar la función de reconexión, definida despues del void setup ()
  }// fin del if (!client.connected())
  client.loop(); // Esta función es muy importante, ejecuta de manera no bloqueante las funciones necesarias para la comunicación con el broker


  //Se construye el string correspondiente al JSON que contiene 3 variables
  String json = "{\"id\":\"HP_PC1\",\"potencia\":"+String(potencia_prom)+",\"energia\":"+String(energia_acc)+"}";
  int str_len = json.length() + 1;//Se calcula la longitud del string
  char char_array[str_len];//Se crea un arreglo de caracteres de dicha longitud
  json.toCharArray(char_array, str_len);//Se convierte el string a char array    

  Serial.print("json enviado: "); Serial.println(char_array); // Se imprime en monitor solo para poder visualizar que el evento sucede
  
  client.publish("capstone_energia/potencia", char_array); // Esta es la función que envía los datos por MQTT, especifica el tema y el valor
}

/*
 * Esta funcion toma mediciones por num_ciclos y despues calcula la potencia del conjunto de meustras
 * 
 */
void medir_voltaje_corriente(){
  if((micros() - t_ciclo) < t_por_ciclo * num_ciclos && muestras_listas == 0)
  {
    tomar_mediciones(); // Se toma un total de muestras de num_muestras_tomadas 
  }
  else
  {
    if(muestras_listas == 1 && (micros() - t_ciclo) > ((t_por_ciclo * num_ciclos) - 3600))
    {
      //Serial.print("Nuevo ciclo "); Serial.print(i_potencia); Serial.print(" : "); Serial.println(micros() - t_ciclo);

      obtener_maximo_minimo(); // Se obtiene el maximo y minimo del conjunto de muestras tomadas
      calcular_potencia(); // Se calcula la potencia del conjunto de muestras tomadas
      calcular_energia();
      //imprimir_parametros();
      
      //delay(910);

      if(corriente_o_voltaje == 0)
      {
        corriente_o_voltaje = 1; // Se mide voltaje para el siguiente conjunto de muestras
      }
      else
      {
        corriente_o_voltaje = 0; // Se mide corriente para el siguiente conjunto de muestras
        corriente_offset = 1;
        inicializar_canal_ADC();
        //int micros_aux = micros();
        //Serial.print("micros ini: "); Serial.println(micros_aux);
        for(int i = 0; i < 5; i++)
        {
          ioffset = leer_ADC() * VPS;
          //Serial.print("offset corriente: "); Serial.println(ioffset);
        }
        //Serial.print("t ioffset: "); Serial.println(micros() - micros_aux);

        //delay(2000);
        i_num_muestras = 0;
        corriente_offset = 0;
      }
      
      //Serial.print("c_o_v: "); Serial.println(corriente_o_voltaje);
      inicializar_canal_ADC(); // Se inicializa el canal del ADC para medir corriente o voltaje segun la variable corriente_o_voltaje
      
      i_potencia ++; // Incrementa el contador para calculos de potencia
      t_ciclo = micros(); // reinicia la variable de tiempo correspondiente
      t_mediciones_tomadas = micros();
      muestras_listas = 0; // limpia la bandera para volver a tomar un conjunto de muestras
    }
  }
}

/*
 * Esta funcion toma una muestra del ADC
 * 
 */
void tomar_mediciones(){
  if((micros() - t_medicion) > t_por_muestra)
  {
    if(i_muestra < num_muestras_tomadas)
    {
      //Serial.print("Muestra tomada "); Serial.print(i_muestra); Serial.print(" ");
      //imprimir_medicion_y_tiempo_en_micros(val);
      t_medicion = micros();
      val = leer_ADC();
      
      muestras[i_muestra] = val * VPS;
      muestras_listas = 0;
      i_muestra++;
    }
    else
    {
      //Serial.println("Muestras de la señal");
      /*for(int i = 0; i < num_muestras_tomadas; i++)
      {
        Serial.print(i); Serial.print(": "); Serial.println(muestras[i]);
      }*/

      //Serial.print("Muestras tomadas: "); Serial.println(i_muestra);
      //Serial.print("t: "); Serial.println((micros() - t_mediciones_tomadas));
      //delay(1000);
      
      i_muestra = 0;
      muestras_listas = 1;
      t_mediciones_tomadas = micros();
    }
  }
}

/**
 * Esta funcion calcula la potencia a partir de las mediciones de voltaje y corriente
 * 
 */
void calcular_potencia(){
  //voffset = v_acc/(num_muestras_tomadas - 4);

  vrms = sqrt(v2/(num_muestras_tomadas - 4));
  irms = sqrt(i2/(num_muestras_tomadas - 4));

  potencia = vrms * irms;
  potencia_acc += potencia;

  //Serial.print("potencia: "); Serial.println(potencia);
  //imprimir_parametros();
}


/**
 * Esta funcion calcula la energia a partir del calculo de potencia
 * 
 */
void calcular_energia(){
  energia = potencia * t_por_calculo_potencia/(150*1000000);
  energia_acc += energia;
}

/*
 * Esta funcion obtiene el maximo y minimo de las muestras tomadas y realiza el calculos para la potencia,
 * encontrando el voltaje al cuadrado y la corriente al cuadrado
 * 
 */
void obtener_maximo_minimo(){
  // Se inicializa las variables de los maximo y minimo para corriente (corriente_o_voltaje = 0) o voltaje (corriente_o_voltaje = 1)
  maximo[corriente_o_voltaje] = -1.0;
  minimo[corriente_o_voltaje] = 6.0;

  //Serial.print("c_o_v max min: "); Serial.println(corriente_o_voltaje);
  if(corriente_o_voltaje == 0)
  {
    //Serial.println("Corriente");
    i2 = 0; // Se inicializa la variable de corriente al cuadrado
  }
  else
  {
    //Serial.println("Voltaje");
    v2 = 0; // Se inicializa la variable de voltaje al cuadrado
    v_acc = 0;
    for(int i = 4; i < num_muestras_tomadas - 4; i++)
    {
      v_acc += muestras[i];
    }
    voffset = v_acc/(num_muestras_tomadas - 8);
  }

  

  
  for(int i = 4; i < num_muestras_tomadas - 4; i++)
  {
    // Se revisa para el valor maximo del conjunto de muestras
    if(muestras[i] > maximo[corriente_o_voltaje])
    {
      maximo[corriente_o_voltaje] = muestras[i]; 
    }

    // Se revisa para el valor minimo del conjunto de muestras
    if(muestras[i] < minimo[corriente_o_voltaje])
    {
      minimo[corriente_o_voltaje] = muestras[i];
    }

    
    if(corriente_o_voltaje == 0)
    {
      // Se realiza el calculo para la corriente al cuadrado
      corriente = (muestras[i] - ioffset) * i_ganancia; // Se resta la componente de offset y se multiplica por la ganancia
      i2 += pow(corriente,2); // Se calcula la corriente al cuadrado
      //Serial.print("corriente "); Serial.print(i); Serial.print(": "); Serial.println(corriente); 
    }
    else
    {
      // Se realiza el calculo para el voltaje al cuadrado
      voltaje = (muestras[i] - voffset) * v_ganancia; // Se resta la componente de offset y se multiplica por la ganancia

      v2 += pow(voltaje,2); // Se calcula el voltaje al cuadrado
    }
    
    muestras[i] = 0; // Se limpia el arreglo para la siguiente toma de muestras
  }
}

/*
 * Esta funcion inicializa uno de los canales del ADC para tomar muestras
 * Se escriben tres bytes al ADC:
 * Byte 1: Se indica que se escribe al registro de configuracion
 * Byte 2: Se especifican los bits 15-8 del registro de configuracion
 * Byte 3: Se especifican los bits 7-0 del registro de configuracion
 * 
 */
void inicializar_canal_ADC(){

  writeBuf[0] = 1; // Puntero al registro de configuracion que es 1

  if(corriente_o_voltaje == 0)
  {
    if(corriente_offset == 0)
    {
      //Serial.println("Corriente mediciones");
      writeBuf[1] = 0b11000000; // Bits 15-8: Inicializa el pin A0, en donde esta el sensor de corriente
      // 0xC0: Modo Single Shot / AIN 0 & GND / 6.144V / Modo Continuo
    }
    else
    {
      //Serial.println("Corriente offset");
      writeBuf[1] = 0b11100000; // Bits 15-8: Inicializa el pin A2 para medir offset del sensor de corriente
      // 0xE0: Modo Single Shot / AIN 2 & GND / 6.144V / Modo Continuo
    }

  }
  else
  {
    //Serial.println("Voltaje mediciones");
    writeBuf[1] = 0b11010000; // Bits 15-8: Inicializa el pin A1, en donde esta el sensor de voltaje
    // 0xD0: Modo Single Shot / AIN 1 & GND / 6.144V / Modo Continuo
  }
  
  //Serial.print("pin: "); Serial.println(writeBuf[1],HEX);
  
  // bit 15 flag bit for single shot
  // Bits 14-12 input selection:
  // 100 ANC0; 101 ANC1; 110 ANC2; 111 ANC3 (Single end)
  // Bits 11-9 Amp gain. Default to 010 here 001 P19
  // Bit 8 Operational mode of the ADS1115.
  // 0 : Continuous conversion mode
  // 1 : Power-down single-shot mode (default)

  // 000 // 2/3x gain +/- 6.144V  1 bit = 3mV      0.1875mV (default)
  // 001 // 1x gain   +/- 4.096V  1 bit = 2mV      0.125mV
  // 010 // 2x gain   +/- 2.048V  1 bit = 1mV      0.0625mV
  // 011 // 4x gain   +/- 1.024V  1 bit = 0.5mV    0.03125mV
  // 100 // 8x gain   +/- 0.512V  1 bit = 0.25mV   0.015625mV
  // 101 - 111 // 16x gain  +/- 0.256V  1 bit = 0.125mV  0.0078125mV

  writeBuf[2] = 0b11100101; //Bits 7-0: 0xE5 / 860 SPS 
  
  // Bits 7-5 data rate default to 111 for 860SPS
  // Bits 4-0 comparator functions see spec sheet. Para este caso no aplica

  // Inicializar el ADS1115
  // Escribir al registro de configuracion
  Wire.beginTransmission(ASD1115);  // ADC 
  Wire.write(writeBuf[0]); // pointer to config register which is 1
  Wire.write(writeBuf[1]); // MSB of config register
  Wire.write(writeBuf[2]); // LSB of config register
  Wire.endTransmission();
}

/*
 * Esta funcion lee un valor del ADC. 
 * Se envia 1 byte indicando solicitando la lectura de un canal
 * Se reciben 2 bytes con esa lectura
 * 
 */
int leer_ADC(){
  int val = 0;
  buffer[0] = 0; // Puntero al registro de conversion que es 0

  // write to pointer register
  Wire.beginTransmission(ASD1115);  // DAC
  Wire.write(buffer[0]);  // Points to conversion register which is 0
  Wire.endTransmission();

  // read conversion register
  Wire.requestFrom(ASD1115, 2);
  buffer[1] = Wire.read();  // MSB(Byte Mas Significativo, bits 15-8) of conversion register
  buffer[2] = Wire.read();  // LSB(Byte Menos Significativo, bits 7-0) of conversion register
  Wire.endTransmission();  

  // convert display results
  val = buffer[1] << 8 | buffer[2]; // Se juntan los dos bytes para obtener la medicion
  
  if (val > 32768) val = 0; // En caso de una lectura erronea, se toma como 0

  i_num_muestras ++;
  
  return val;
}

/*
 * Esta función inicializa el WiFi 
 * 
 */
void setup_wifi() {
 
  delay(10);
  // We start by connecting to a WiFi network
  Serial.println();
  Serial.print("Connecting to ");
  Serial.println(ssid);
 
  WiFi.begin(ssid, password);
 
  while (WiFi.status() != WL_CONNECTED) {
    delay(500);
    Serial.print(".");
  }
 
  Serial.println("");
  Serial.println("WiFi connected");
  Serial.println("IP address: ");
  Serial.println(WiFi.localIP());
}

// Esta función permite tomar acciones en caso de que se reciba un mensaje correspondiente a un tema al cual se hará una suscripción
void callback(char* topic, byte* message, unsigned int length) {

  // Indicar por serial que llegó un mensaje
  Serial.print("Llegó un mensaje en el tema: ");
  Serial.print(topic);

  // Concatenar los mensajes recibidos para conformarlos como una varialbe String
  String messageTemp; // Se declara la variable en la cual se generará el mensaje completo  
  for (int i = 0; i < length; i++) {  // Se imprime y concatena el mensaje
    Serial.print((char)message[i]);
    messageTemp += (char)message[i];
  }

  // Se comprueba que el mensaje se haya concatenado correctamente
  Serial.println();
  Serial.print ("Mensaje concatenado en una sola variable: ");
  Serial.println (messageTemp);

  // En esta parte puedes agregar las funciones que requieras para actuar segun lo necesites al recibir un mensaje MQTT

  // Ejemplo, en caso de recibir el mensaje true - false, se cambiará el estado del led soldado en la placa.
  // El ESP323CAM está suscrito al tema esp/output
  if (String(topic) == "esp32/outputfdrc") {  // En caso de recibirse mensaje en el tema esp32/outputfdrc
    if(messageTemp == "true"){
      Serial.println("Led encendido");
    }// fin del if (String(topic) == "esp32/outputfdrc")
    else if(messageTemp == "false"){
      Serial.println("Led apagado");
    }// fin del else if(messageTemp == "false")
  }// fin del if (String(topic) == "esp32/outputfdrc")
}// fin del void callback

// Función para reconectarse
void reconnect() {
  // Bucle hasta lograr conexión
  while (!client.connected()) { // Pregunta si hay conexión
    Serial.print("Tratando de contectarse...");
    // Intentar reconexión
    if (client.connect("ESP32CAMClient")) { //Pregunta por el resultado del intento de conexión
      Serial.println("Conectado");
      client.subscribe("esp32/outputfdrc"); // Esta función realiza la suscripción al tema
    }// fin del  if (client.connect("ESP32CAMClient"))
    else {  //en caso de que la conexión no se logre
      Serial.print("Conexion fallida, Error rc=");
      Serial.print(client.state()); // Muestra el codigo de error
      Serial.println(" Volviendo a intentar en 5 segundos");
      // Espera de 50 milisegundos bloqueante
      delay(5000);
      Serial.println (client.connected ()); // Muestra estatus de conexión
    }// fin del else
  }// fin del bucle while (!client.connected())
}// fin de void reconnect(
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
